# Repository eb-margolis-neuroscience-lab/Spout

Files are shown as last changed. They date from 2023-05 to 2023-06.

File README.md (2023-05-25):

# Spout
This is the general repository where all Spout related information can be found. 

Spout is a device that tracks rodent liquid consumption in a home cage environment. It can be built by any individual with minimnal soldeirng experience and is cost effective. This repository includes the [construction guide](https://github.com/eb-margolis-neuroscience-lab/Spout/tree/main/Spout_Construction_Guide), [arduino code for the device](https://github.com/eb-margolis-neuroscience-lab/Spout/tree/main/arduino%20code), and the [anaylsis software](https://github.com/eb-margolis-neuroscience-lab/Spout/tree/main/SpoutAnalyze) that was created for the device. You can find the Spout publication [here]().

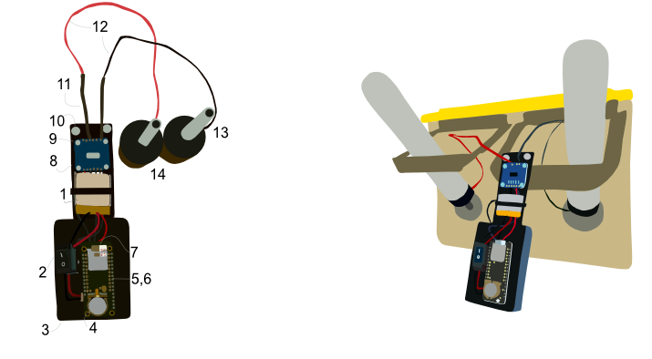
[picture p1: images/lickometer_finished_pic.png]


## [Device contruction guide](https://github.com/eb-margolis-neuroscience-lab/Spout/tree/main/Spout_Construction_Guide)

The contruction guide describes how to build the Spout device. It includes links to all the necessary components, 3D print files, wiring diagrams, soldering tutorials, and all details needed for an electrical engineering novice to build this device. Accessibility was an important factor when creating Spout. The device is cost effective and can be built by anyone, regardless of electrical engineering experience. The soldering tutorials linked in the construction guide should an adequate introcution to master the limited soldering needed to build the device. 

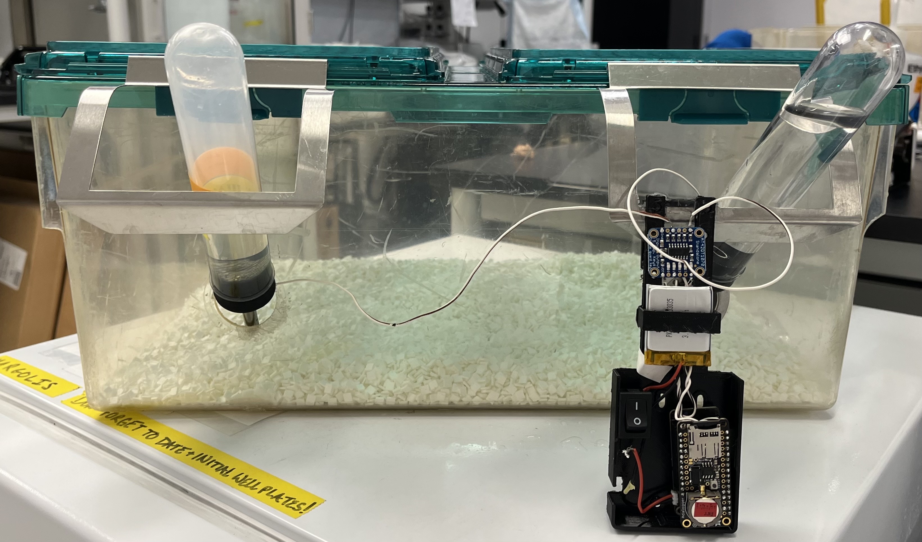
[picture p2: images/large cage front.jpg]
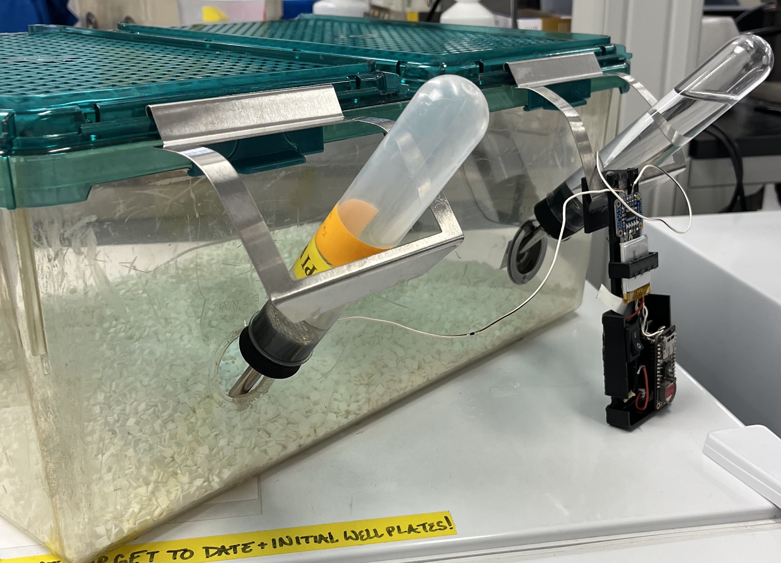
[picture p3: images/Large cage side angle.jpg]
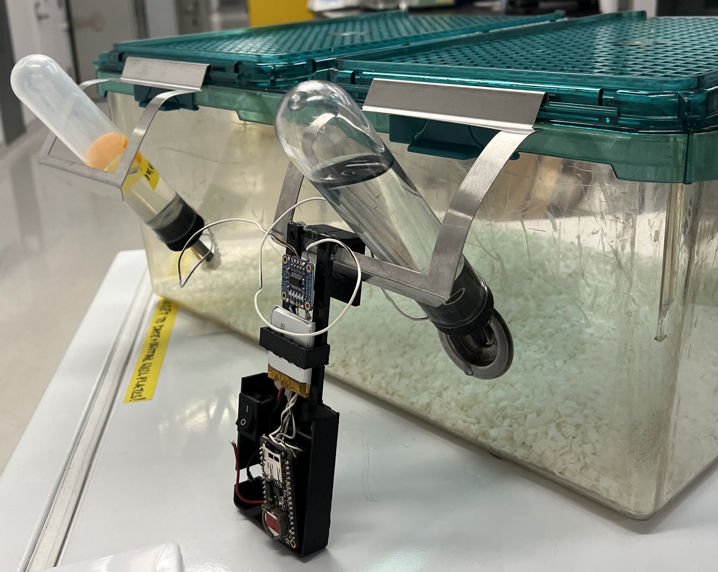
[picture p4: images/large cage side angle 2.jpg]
  

## [Code for device](https://github.com/eb-margolis-neuroscience-lab/Spout/tree/main/arduino%20code)

The arduino code folder includes the real time clock code, which must be flashed onto the device to set the coin battery clock prior to the SpoutCollect code, and the most updated C++ file (SpoutCollect.ino) that tells the device how to collect data. The user must download these files onto their computer, and then starting with pcf8523, the user uploads the two files onto the Spout device that is connected to the computer with a micro USB cable. In the arduino code folder there are links to adruino tutorials to help people that do not have much programming experience. 

## [SpoutAnalyze desktop data analysis app](https://github.com/eb-margolis-neuroscience-lab/Spout/tree/main/SpoutAnalyze)

SpoutAnalyze is the analysis software that is downloaded onto the users computer in order to analyze the collected csv files into useable data. The user takes the csv files off the microSD card that collects the data directly from the device, and uploads these files into SpoutAnalyze. SpoutAnalyze reads the csv files and produces time-locked consumption graphs, estimated total volume consumed, total bout time,  longest bout, median bout time, and drinking bout length histograms for each spout. It also has the function to summarize groups of data at once under the "analyze group" tab. This folder also includes a video tutorial explaining how to use the program.

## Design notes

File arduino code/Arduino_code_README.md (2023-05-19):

# Firmware installation  
 1. If you don't already have it, install the [Arduino IDE](https://www.arduino.cc/en/software) which will upload the compiled code to the device. Then follow the [instructions](https://learn.adafruit.com/adafruit-esp32-feather-v2/arduino-ide-setup) on the Adafruit website to install the required libraries for the Huzzah32. 
 2. The real time clock (RTC) will hold the date and time so that data can be aligned with time of day. Follow [these instructions](https://learn.adafruit.com/adafruit-pcf8523-real-time-clock/rtc-with-arduino), except the wiring part, to set the RTC. 
 3. To set the RTC, connect the Spout device to the computer with a microUSB and flash [RTC_PCF8523](https://github.com/eb-margolis-neuroscience-lab/Spout/blob/main/arduino%20code/pcf8523.ino) onto it. The clock will be set based on the time and date on the computer. To check that the clock is set and functioning open the Arduino IDE serial monitor with the device still connected to the computer. If the coin battery gets disconnected at any time, the RTC has to be flashed onto the device again. 
4. Use the Arduino IDE to flash [SpoutCollect](https://github.com/eb-margolis-neuroscience-lab/Spout/blob/main/arduino%20code/SpoutCollectMay2023.ino) onto the device. 
5. Disconnect the device from the computer and insert a micro SD card. 
6. The device is ready to use once the battery is inserted. Click [here](https://github.com/eb-margolis-neuroscience-lab/Spout/blob/main/Spout_Construction_Guide/Spout_Construction_Guide_README.md) to return to the contruction guide. 

## Helpful tutorials for Arduino IDE and C++: 

1. [Arduino IDE basics](https://docs.arduino.cc/software/ide-v1/tutorials/arduino-ide-v1-basics)

2. [Arduino IDE intro tutorial](https://docs.arduino.cc/learn/starting-guide/the-arduino-software-ide) -- This tutorial allows you to learn how to navigate Arduino IDE by creating your own blink program. This is not a needed step for using Spout, it is just a helpful resource for people that are new to Arduino and programming. 

3. [Introduction to C++ on Arduino](https://www.digikey.com/en/maker/blogs/2020/the-basics-of-c-on-an-arduino-part-1-variables)

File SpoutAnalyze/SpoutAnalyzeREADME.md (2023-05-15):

# SpoutAnalyze
A comprehensive application that works together with the SpoutCollect home cage drinking tracking device to analyze and visualize recorded data. The app is written in [`electron.js`](https://github.com/electron/electron) and runs as an independent executable. The app processes and summarizes the SpoutCollect data, output including visualing bout v time of day and estimated consumption volumes. The app also can generate reference calibrations to relate drinking duration to volume consumed.  
Graphics are generated using [`plotly.js`](https://plotly.com/javascript/), and can be saved as vector graphics. <br>

A link to the Spout journal article can be found here. (to be added)

## Example Workflow Video: Calibration Page
HomePage

## Installing
To install **SpoutAnalyze**, go to the [`SpoutJS SourceForge Page`](https://sourceforge.net/u/ahberson/profile) and follow the instructions for your computer's platform. Apple, Windows, and Linux versions are downloadable.

## Getting Started
See the Spout device construction guide to get started collecting data.

### Analyze one file

### Analyze a group of files

### Generate a calibration curve
The calibration curve function enables consumed volumes to be estimated from the drinking durations detected. The last active calibration is automatically loaded when the app is launched and is used by the "analyze" functions. Calibrations can be exported and imported in case multiple calibration curves are required by a user. <br>

We recommend collecting data from at least 8 animals (or 16 bottles) for a calibration. <br>

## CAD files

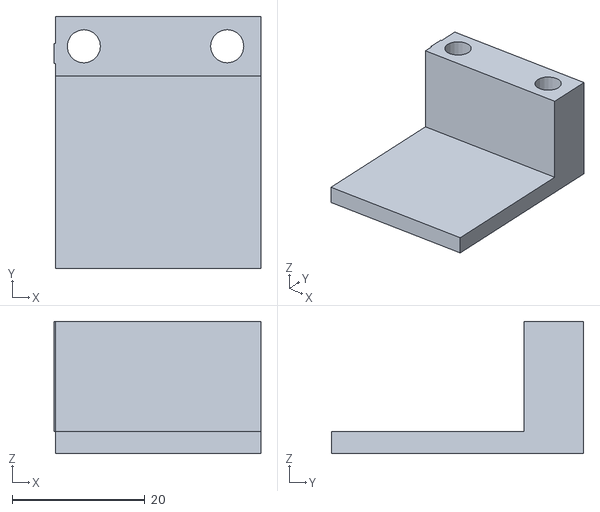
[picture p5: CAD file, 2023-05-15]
Spout_Construction_Guide/Spout hook (1).stl
31.2 x 38.0 x 19.9

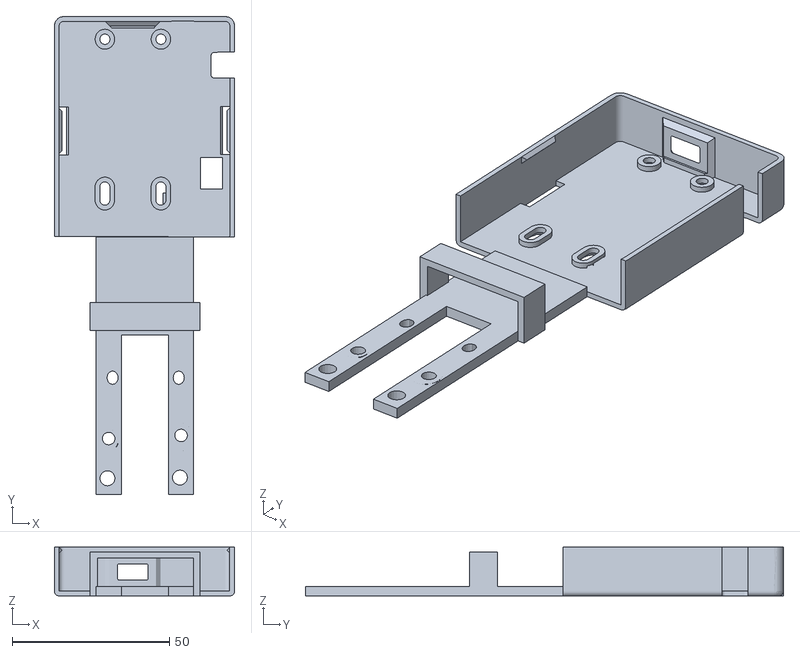
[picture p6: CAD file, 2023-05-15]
Spout_Construction_Guide/Spout body final (1).stl
57.2 x 151.8 x 15.5

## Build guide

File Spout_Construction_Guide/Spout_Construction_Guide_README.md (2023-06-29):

# Spout construction guide
This guide explains how to assemble the Margolis Lab Spout, a cost effective device that tracks rodent liquid consumption in the animal's home cage for up to two different bottles. The device collects data and the desktop app ['SpoutAnalyze'](https://github.com/eb-margolis-neuroscience-lab/SpoutJS-LIQR) analyzes it and generates visualizations. 
A link to the Spout journal article [will be] found here ()
## Materials 

| | Component | Number | Cost per unit | Total cost | Source|
|-|---|---|---|---|---|
| 1 | Lithium ion battery (capacity = 500mAh) | 1| $7.95 | $7.95 | [Adafruit Lithium Ion Battery](https://www.adafruit.com/product/1578) |
| 2 | Switch | 1 | $1.72 | $1.72 | [Switch](https://www.digikey.com/en/products/detail/triad-components-group,-inc/RF1-1B-DC-2-B-1/11492841?utm_adgroup=Triad%20Components%20Group%2C%20INC&utm_source=google&utm_medium=cpc&utm_campaign=Shopping_DK%2BSupplier_Tier%201%20-%20Block%201&utm_term=&utm_content=Triad%20Components%20Group%2C%20INC&gclid=EAIaIQobChMI2vfoy7Ca_AIVKQ2tBh3Y_wqhEAQYASABEgJIcvD_BwE) |
| 3 | 3D printed Case | 1 | Cost depends on plastic used |  | [3d Printed case]()
| 4 | Coin Battery | 1 | ~$1 | ~$1 | [Panasonic CR1220 3V coin battery](https://www.panasonic-batteries.com/en/specialty/lithium-coin/coin-lithium-cr1220) |
| 5 | Adafruit Feather Huzzah 32 | 1 | $19.95 | $19.95 | [Adafruit Feather Huzzah32](https://www.adafruit.com/product/3405) |
| 6 | Adafruit Adalogger FeatherWing | 1 | $8.95 | $8.95 | [Adafruit Adalogger Featherwing](https://www.adafruit.com/product/2922) |
| 7 | SanDisk MicroSD card 16GB | 1 | ~$5 | ~$5 | [SanDisk MicroSD 16GB 3-pack](https://www.amazon.com/SanDisk-3-Pack-microSDHC-Memory-3x16GB/dp/B089DPCJS1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) |
| 8 | Standalone 5 Key Capacitive Touch Sensor | 1 | $7.50 | $7.50 | [Adafruit capacitive touch sensor](https://www.adafruit.com/product/1362) |
| 9 | Small screws and nuts to secure boards | 8 |  | | [screws]() |
| 10 | Large screws and nuts for case | 2 | | | [large screws]() | 
| 11 | Heat shrink |  | $0.01 | $0.01 | [Heat Shrink](https://www.amazon.com/625pcs-Shrink-Tubing-Tubes-Ratio/dp/B07QM8249H?th=1) |
| 12 | Wires | 6 | $0.65/foot| $1.95 | [Stranded electrical wire](https://www.amazon.com/BNTECHGO-Silicone-Flexible-Strands-Stranded/dp/B01MFEV8SG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) |
| 13 | Metal spout | 2 | | | [metal sipper tube](https://www.altdesign.com/products/rodent-ivc/rodent-ivc-accessories/watering-options/water-bottles/water-bottle-sipper-tubes/straight-tube-with-ball-stainless-steel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) |
| 14 | Rubber stopper with hole | 2 | | | [rubber stopper with hole](https://www.fishersci.com/shop/products/rubber-stopper-size-6-1-hole-5mm-diameter/S24600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) |

## Case 
The 3D print files for the case can be found here: [Spout body](https://github.com/eb-margolis-neuroscience-lab/lick-o-meter-construction-guide/blob/main/Spout%20body%20final.stl) and [Spout hook](https://github.com/eb-margolis-neuroscience-lab/lick-o-meter-construction-guide/blob/main/Spout%20hook.stl)

Use 2 large screws to secure the neck of the case to the hook so that Spout can hang off the homecage. See [Securing the boards to the case](https://github.com/eb-margolis-neuroscience-lab/lick-o-meter-construction-guide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) for more information. 

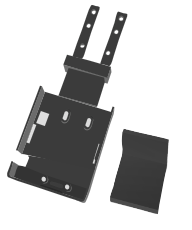
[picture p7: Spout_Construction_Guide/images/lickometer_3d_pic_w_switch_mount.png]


## Wiring the adafruit and adalogger boards 

1. Solder the female headers to the Huzzah32 Board. Soldering tips can be found here: ['How_to_solder'](https://www.youtube.com/watch?v=6rmErwU5E-k) ['Soldering_headers'](https://learn.adafruit.com/how-to-solder-headers/overview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) 
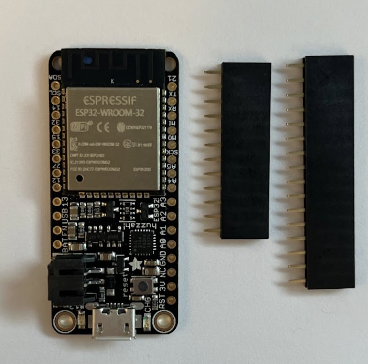
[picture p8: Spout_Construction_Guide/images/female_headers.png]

2. Solder the male headers to the adalogger feather board.
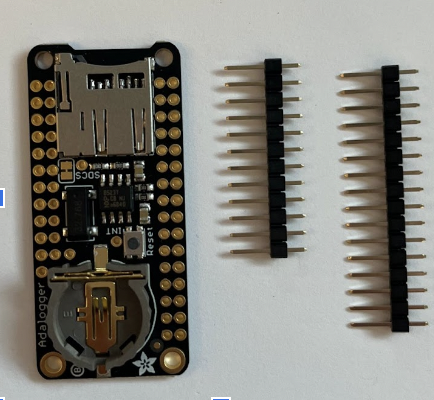
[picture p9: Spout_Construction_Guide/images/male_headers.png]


3. Solder four wires to their respective pins on the Adalogger feather board. The wires are soldered to the adalogger board, but the Huzzah32 board has the pin labels. Solder the wires such that wire 1 is attached to the ground pin (**GND**) wire 2 is attached to power pin (**3V**), and the two input signal wires are attached to pins **A0** and **A7**. 

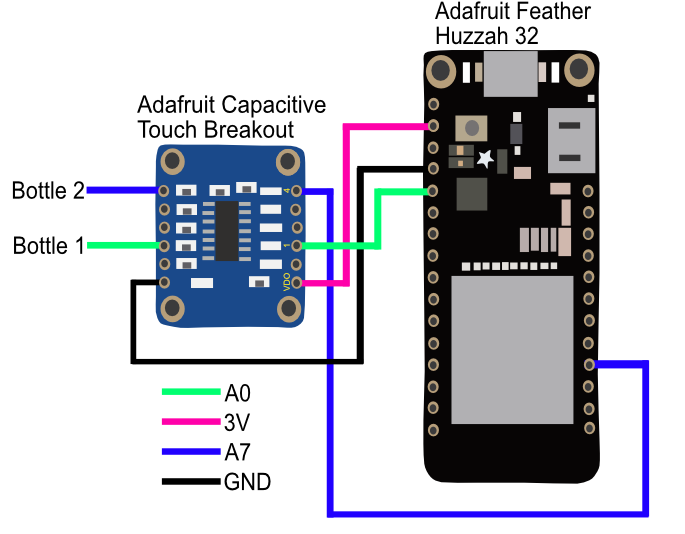
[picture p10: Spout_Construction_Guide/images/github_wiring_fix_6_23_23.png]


4. Solder the other ends of the four wires to their pins on the **output** side of the Capacitive touch breakout board. **3V** to **VDO**, **GND** to **GND**, **A7** to pin **4**, **A0** to pin **1**. 

### How to modify the wires to fit your metal bottle spouts:
 
 Take two wires and strip 2.5-3 cm of the insulation from one end. Wrap the exposed wire around the base of your metal bottle spout. Solder the wire in a circle that fits snugly around the metal sipper tube. 

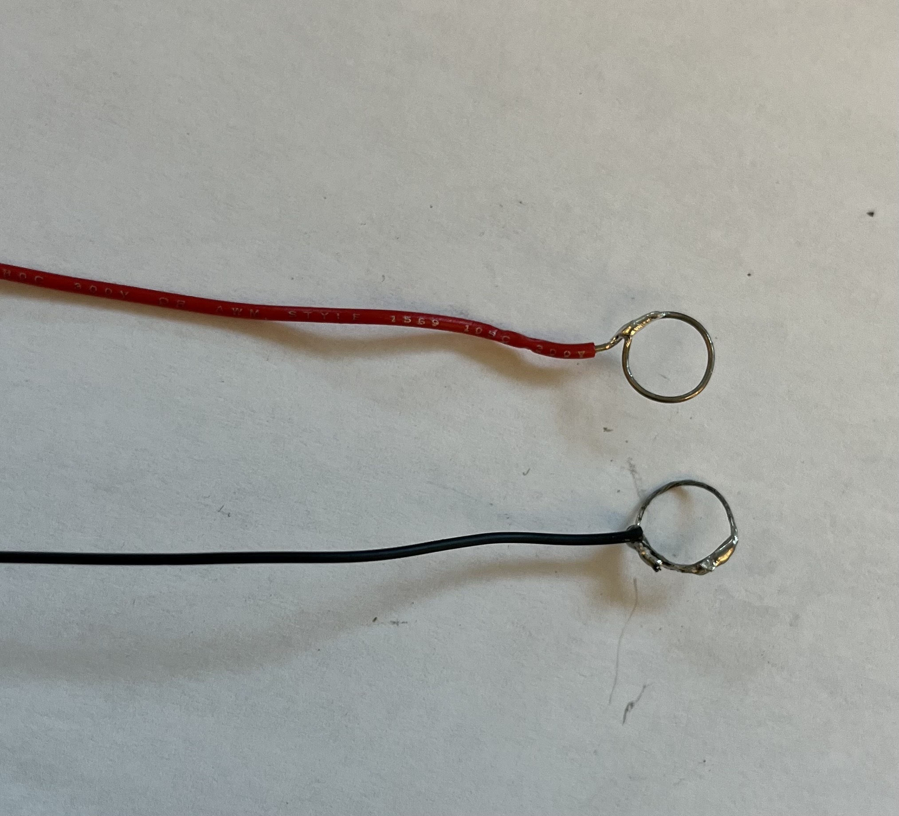
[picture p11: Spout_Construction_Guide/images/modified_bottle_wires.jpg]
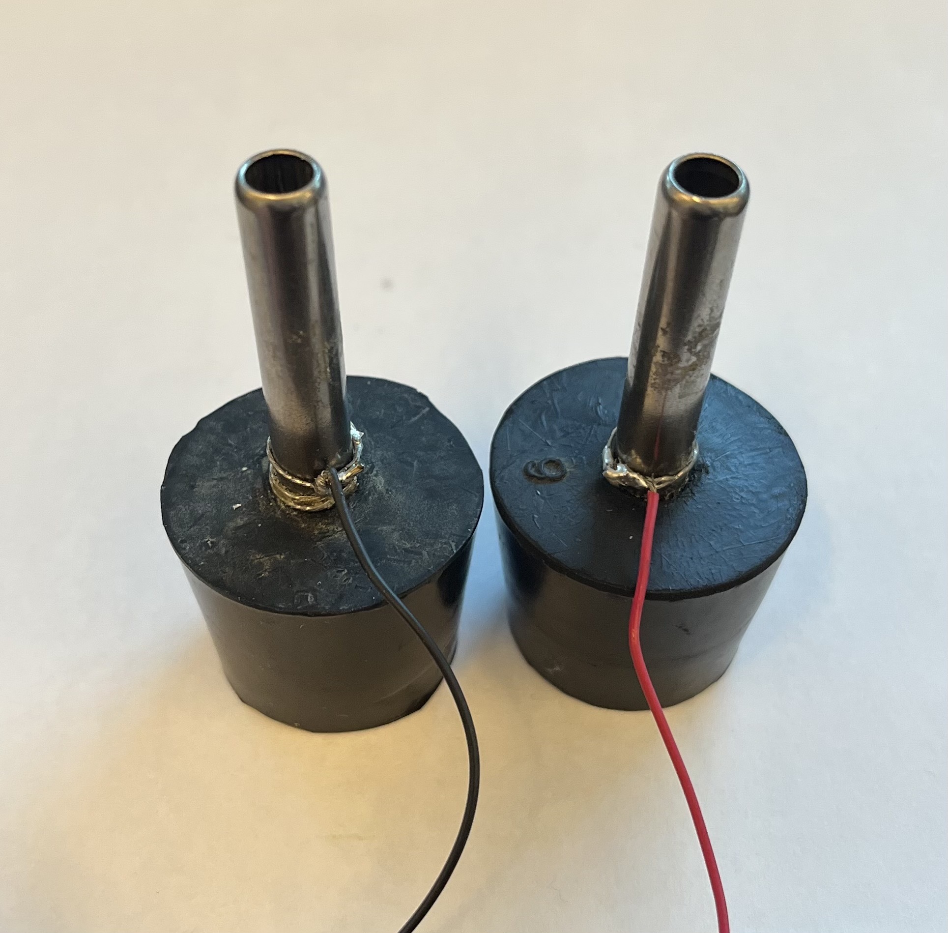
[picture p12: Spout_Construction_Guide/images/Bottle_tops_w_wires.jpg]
  

### How to reinforce bottle wire connections
 
 Next these modified wires need to be soldered to the **input** side of the capacitive touch breakout board. This connection undergoes significant and repetitive strain as the bottles are placed and removed. Reinforcement is optional, but we recommend it. You may choose to skip to **step 5**. 
1. Strip about 1.5 cm of coating off the non-modified ends of the bottle wires.

2. Take 2.5 cm long pieces of heat shrink and feed them over each wire.
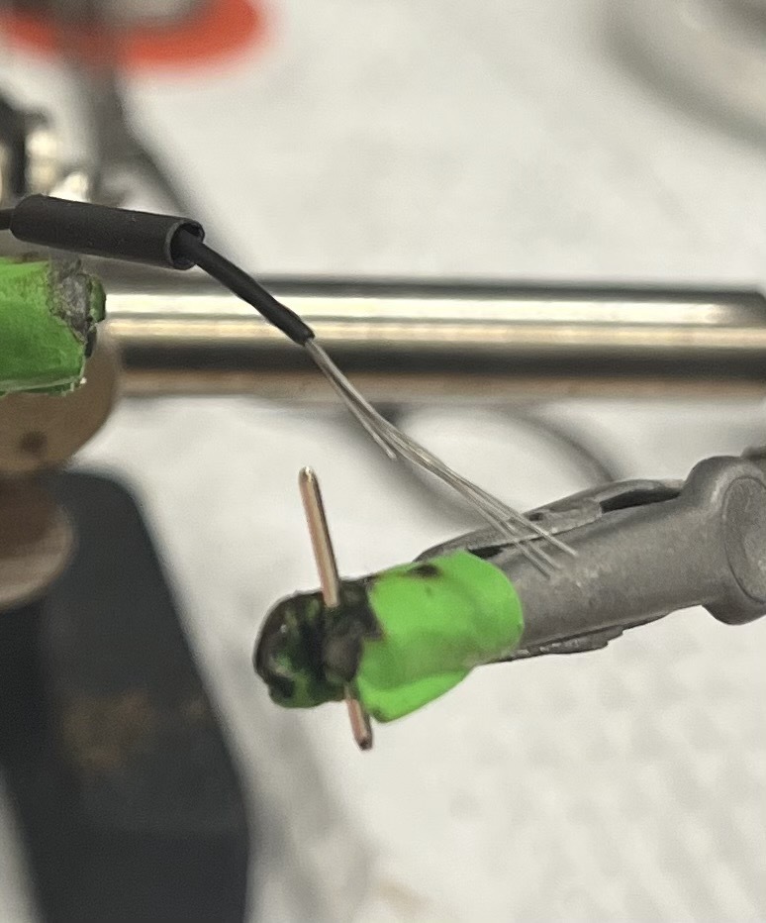
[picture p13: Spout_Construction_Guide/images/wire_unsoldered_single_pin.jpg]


3. Take one single male header pin and solder the long end of the pin to the exposed wire. Repeat on other wire. 
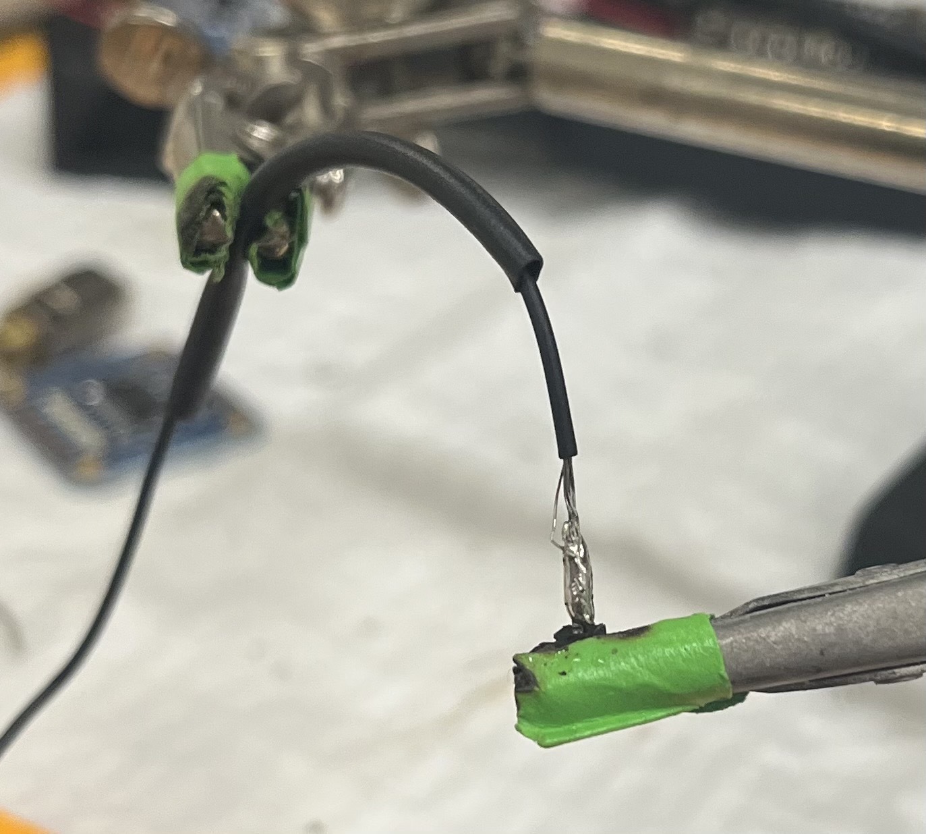
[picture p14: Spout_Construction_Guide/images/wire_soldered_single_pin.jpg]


4. Move heat shrink over the soldered connection between the wire and the male header pin. Heat to secure. Reapeat on other wire. 

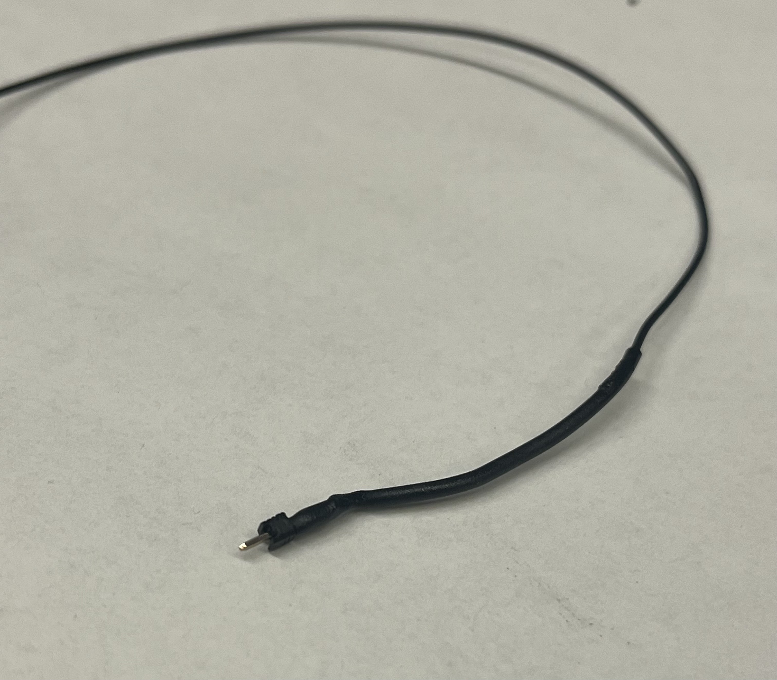
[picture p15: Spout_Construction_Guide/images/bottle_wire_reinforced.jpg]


5. Solder the two modified bottle spout wires to pins **1** and **4** on the **input** side of the Adafruit capacitive touch breakout board. If you reinforced the bottle spout wire connection, solder the short ends of the male header pins into pins 1 and 4. 

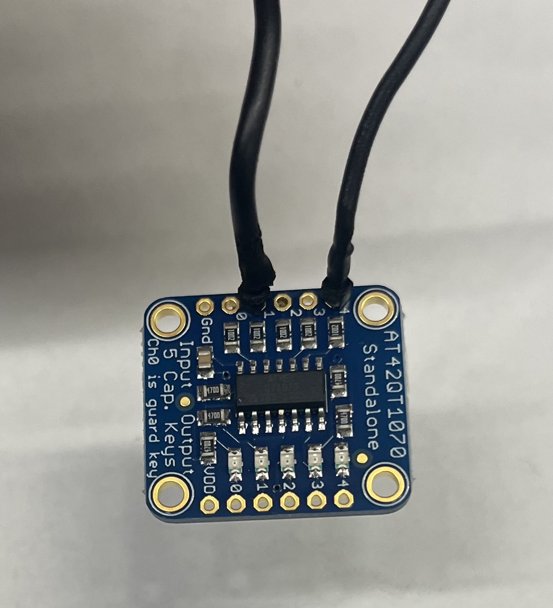
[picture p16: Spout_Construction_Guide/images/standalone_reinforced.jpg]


6. Stack the Adalogger board on top of the Huzzah32 board, lining them up by the header pins. 

7. Insert the coin cell battery into the Adalogger feather board. Note: This battery powers the real time clock (RTC), not the device. This battery is expected to last at least a year, if not longer, but if the date on your Spout files is incorrect, the battery is likely be dead. 

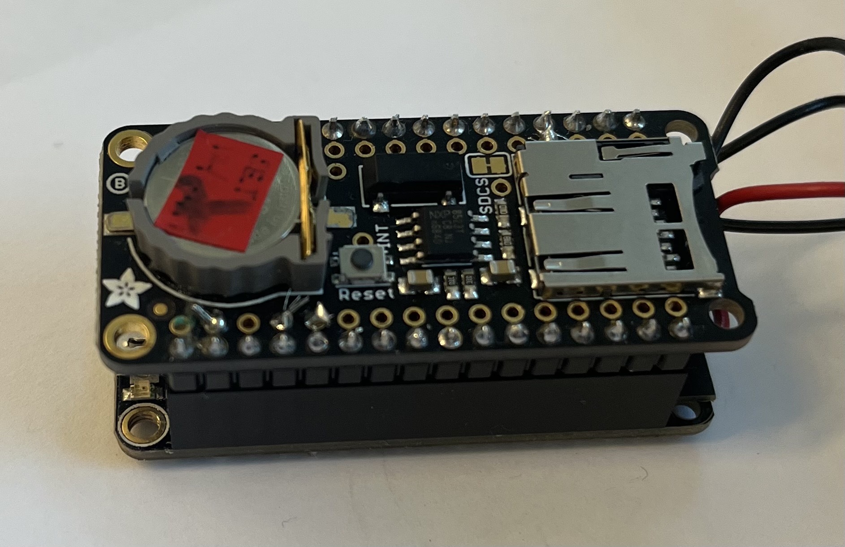
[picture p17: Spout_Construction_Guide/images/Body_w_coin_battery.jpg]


## Securing the boards to the case 

Using screws secure the Huzzah32 and Feather boards to the base of the case and the capacitive sensor board to the neck of the case. 

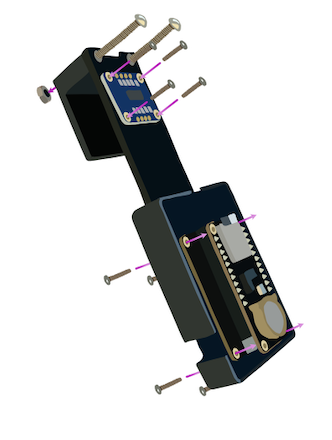
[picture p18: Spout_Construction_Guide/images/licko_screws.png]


## Adding a switch to the lithium battery 

The SpoutCollect device starts writing data immediately when it is powered on. In order to easily start and stop the device after it is mounted in place on the cage we add a switch to the lithium battery that powers the device. We have found that a 3.7 V 500 mAh Li-ion battery is sufficient to run the device for well over 24 hr. Larger capacity batteries can be used as well, as long as the connector is compatible with the Huzzah32. 

1. Cut the **red wire** of the battery at its halfway point. Strip 1 cm of wire insulation from each of the ends just created.

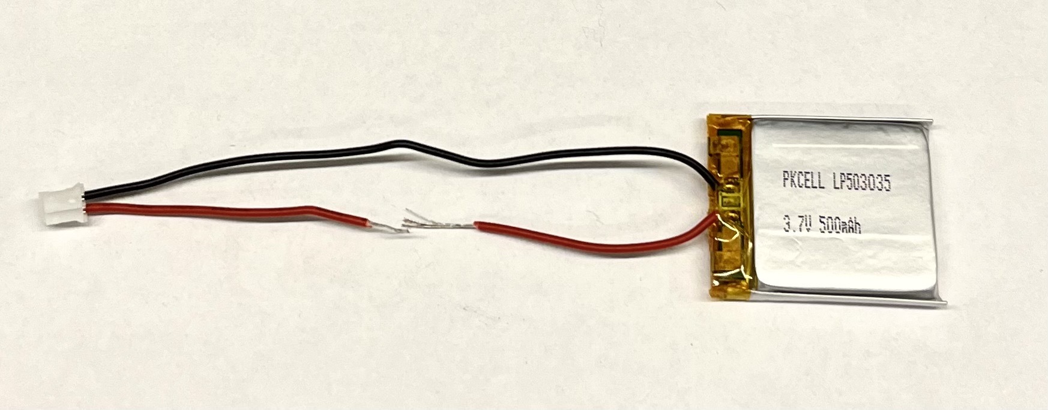
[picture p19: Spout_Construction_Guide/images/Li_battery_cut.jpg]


2. Solder these ends to the leads on the switch.

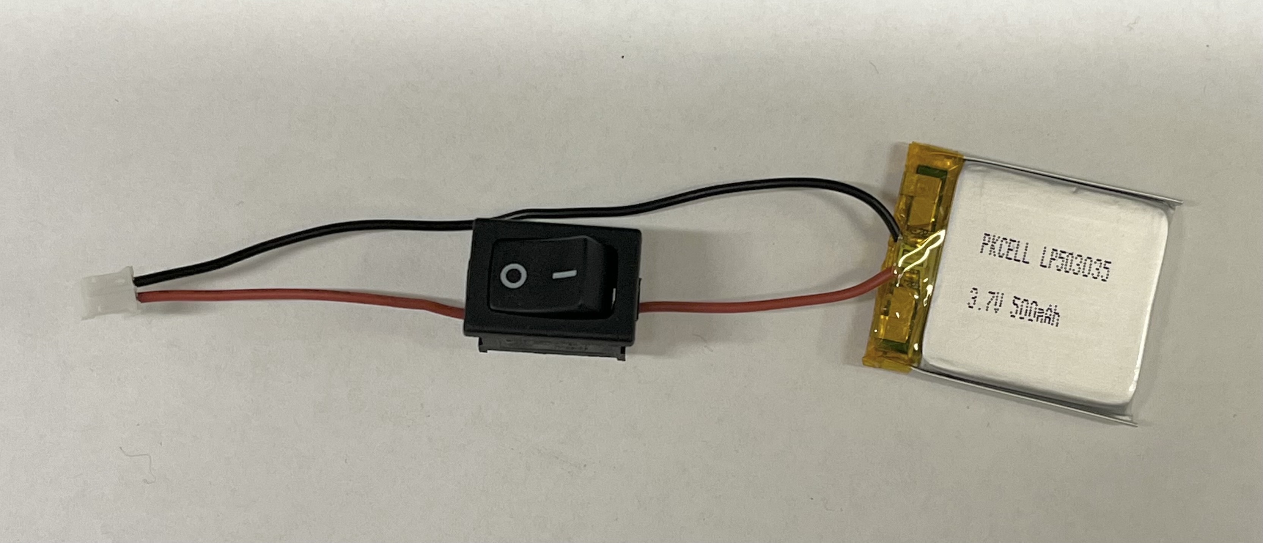
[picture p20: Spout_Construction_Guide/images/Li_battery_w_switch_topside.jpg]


3. The battery slides under the plastic arch on the neck of the case and the legs of the battery fit into the square hole on the body of the case next to the Huzzah32. See graphic below. 

Make sure the switch is in the **ON position** when charging. Charging is acomplished through the micro USB connector.

## Firmware installation  
 1. If you don't already have it, install the [Arduino IDE](https://www.arduino.cc/en/software) which will upload the compiled code to the device. then follow the [instructions](https://learn.adafruit.com/adafruit-esp32-feather-v2/arduino-ide-setup) on the Adafruit website to install the required libraries for the Huzzah32. 
 2. The real time clock (RTC) will hold the date and time so that data can be aligned with time of day. Follow [these instructions](https://learn.adafruit.com/adafruit-pcf8523-real-time-clock/rtc-with-arduino), except the wiring part, to prepare to set the RTC. 
 3. To set the RTC, connect the Spout device to the computer and flash [RTC_PCF8523](https://github.com/eb-margolis-neuroscience-lab/lick-o-meter-construction-guide/blob/main/pcf8523.ino) onto it. The clock will be set based on the time and date on the computer. To check that the clock is set and functioning open the Arduino IDE serial monitor with the device still connected to the computer. 
4. Use the Arduino IDE to flash [SpoutCollect](https://github.com/eb-margolis-neuroscience-lab/lick-o-meter-construction-guide/blob/main/SpoutCollectOct2022.ino) onto the device. 
5. Disconnect the device from the computer and insert a micro SD card. 

## Hanging your device on the homecage 
Here are some images that show how to hang the Spout on two different types of cages: 

  

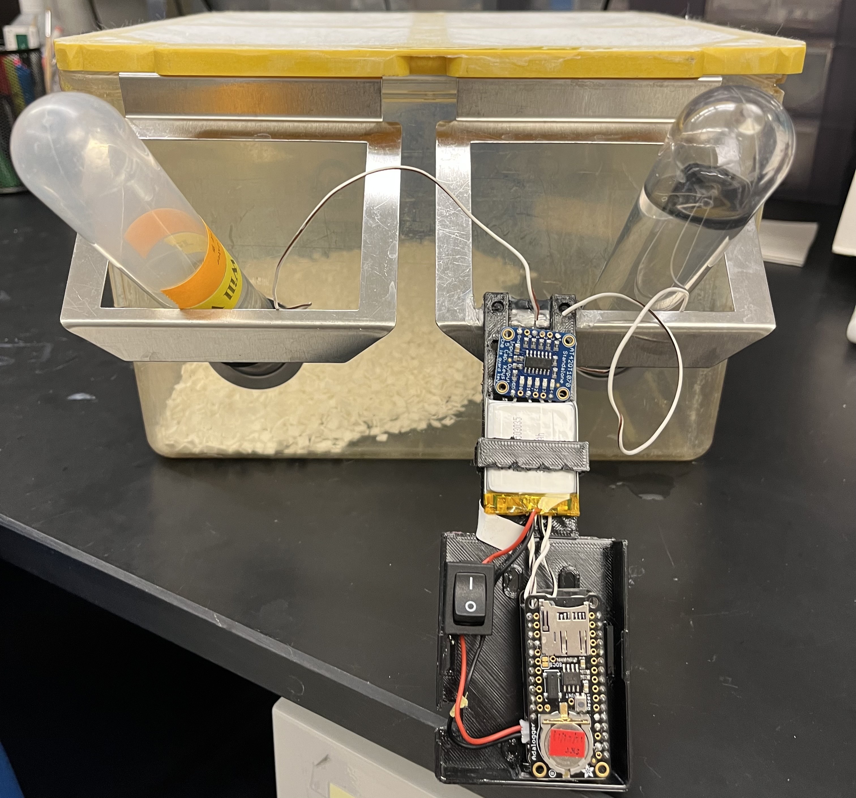
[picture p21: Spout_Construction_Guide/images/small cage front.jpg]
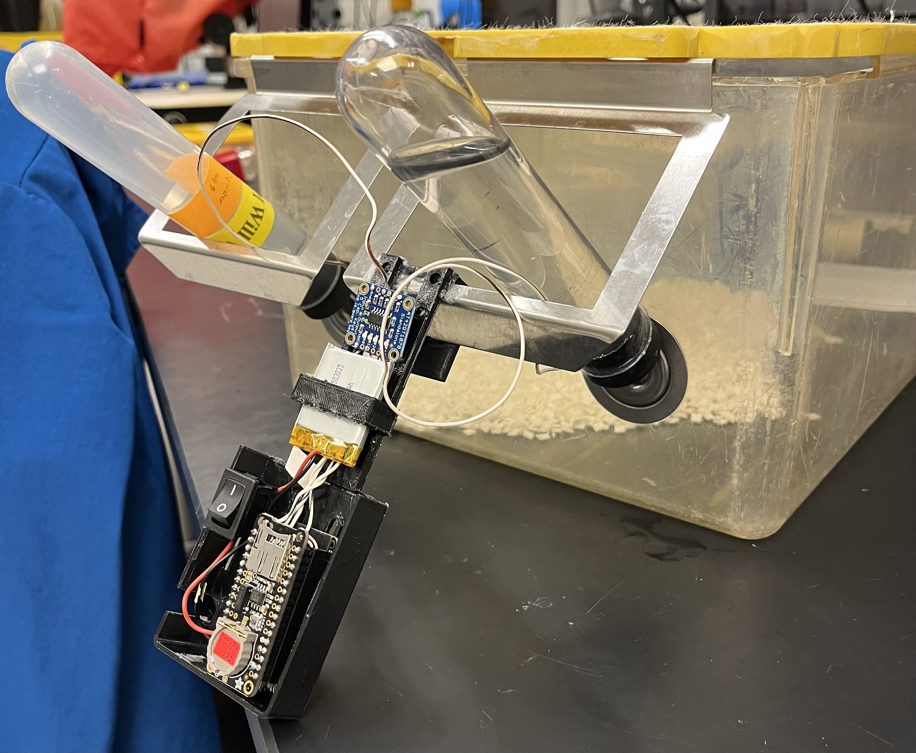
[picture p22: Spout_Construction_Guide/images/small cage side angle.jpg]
 

## Your device is ready for use!

To use, hang on home cage and turn battery switch to ON. To transfer collected data to the computer for analysis remove the microSD card and connect it to the computer using a card reader or adapter. 



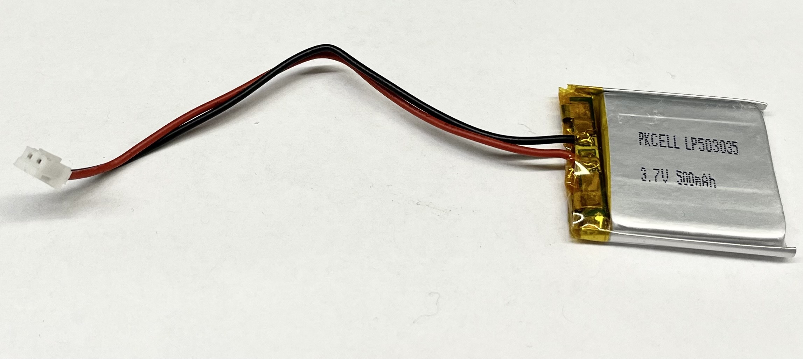
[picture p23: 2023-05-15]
Spout_Construction_Guide/images/Li_Battery_uncut.jpg

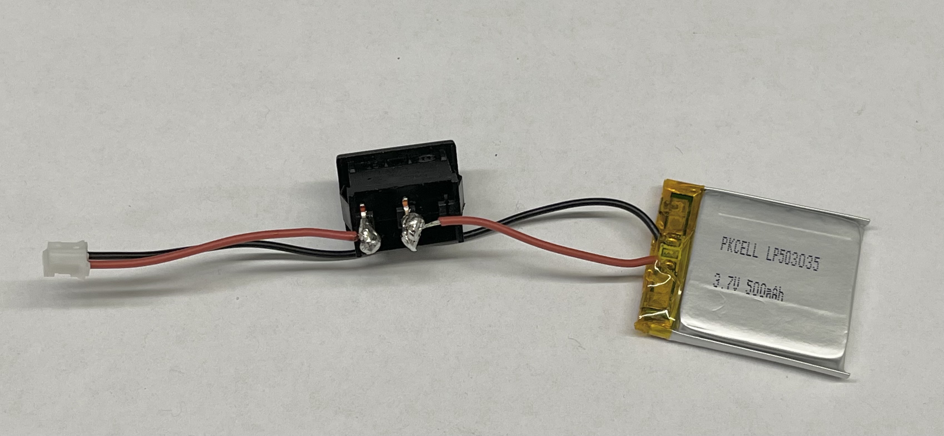
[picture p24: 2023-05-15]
Spout_Construction_Guide/images/Li_battery_with_switch_solder_side.jpg

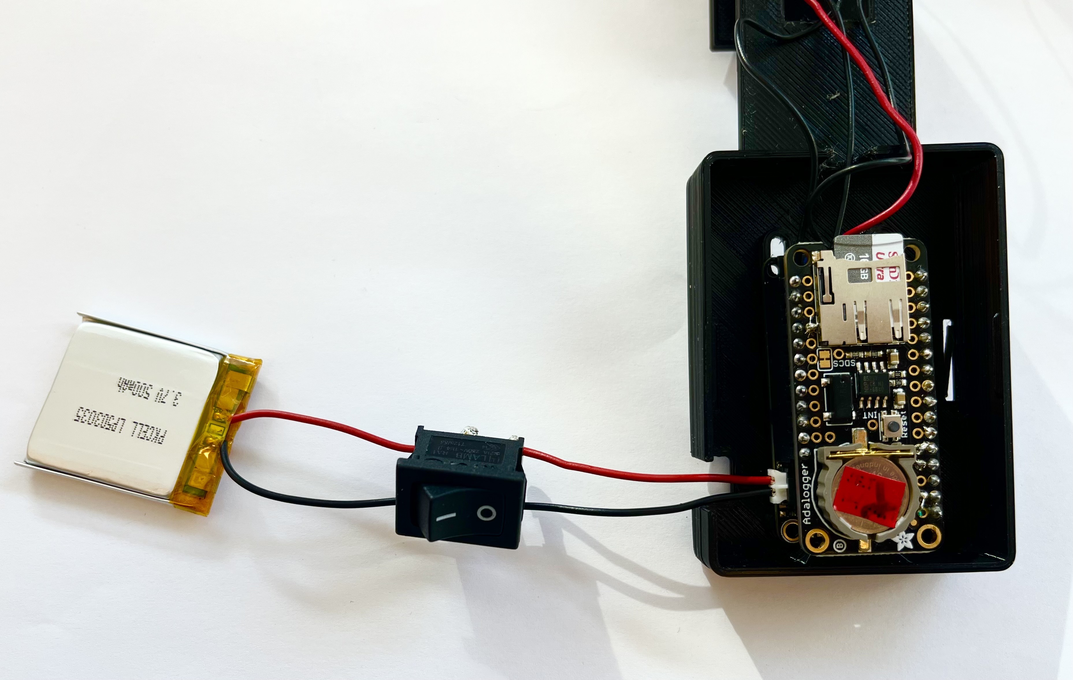
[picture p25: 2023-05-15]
Spout_Construction_Guide/images/Li_battery_with_switch.jpg

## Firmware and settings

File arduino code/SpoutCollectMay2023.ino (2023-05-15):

//SpoutCollect v 0.9.22
//Firmware for rodent cage mounted drinking tracker, capacitative touch detection
//See hardware details at [insert Github link here] 
//Last updated by EBM 5/06/2023

#include <Wire.h>
#include "RTClib.h"
#include "FS.h"
#include "SD.h"
#include "SPI.h"
#include <time.h>
#include <String.h>

RTC_PCF8523 rtc;

char daysOfTheWeek[7][12] = {"Sunday", "Monday", "Tuesday", "Wednesday", "Thursday", "Friday", "Saturday"};
char monthsOfTheYear[13][12] = {"", "January", "February", "March", "April", "May", "June", "July", "August", "September", "October", "November", "December"};

const int TOUCH_RED = A0; //connect breakout pad to pin A0
const int TOUCH_BLACK = A7; //connect breakout pad to pin A7

//GPIO bitmask calculation for sleep functionality
#define BLACK_PIN_BITMASK 0x100000000

float BatteryVoltage = 0;
char filenameSTR[] = "00000000.csv";
const int touch_threshold = 100;

//This device name, used in naming of files
String fname = "Cage1";

//---------------------------------------------------
void setup()
{
  Serial.begin(115200);
  // Initialize SD Card
  if (!SD.begin(33)) {
    Serial.println("Card Mount Failed");
    return;
  }
  uint8_t cardType = SD.cardType();
  if (cardType == CARD_NONE) {
    Serial.println("No SD card attached");
    return;
  }

  //Check RTC
  if (! rtc.begin()) {
    Serial.println("Couldn't find RTC");
    while (1);
  }
  if (! rtc.initialized()) {
    Serial.println("RTC is NOT running!");
  }
  
  //Get start time and date, name datafile accordingly
  DateTime now = rtc.now();
  char dateTimeString[200] = "";
  sprintf(dateTimeString, "%s, %s %d %04d %02d:%02d:%02d", daysOfTheWeek[now.dayOfTheWeek()], monthsOfTheYear[now.month()], now.day(), now.year(), now.hour(), now.minute(), now.second());
  String timestamp = "Begin data collection at ";
  timestamp += dateTimeString;
  String dataString = "";
  dataString += "Touch value BLACK, ";
  dataString += "Touch value RED, ";
  dataString += "Time (ms)";
//  dataString += ", Battery voltage";
//filenamestring must start with / and include _ between device name and timestamp
  String thisfilename = "/";
char filedate ;
  thisfilename = thisfilename + fname + "_"; 
  sprintf(filedate, "%dMonth%dDay%dHour%dMinute.csv", now.month(), now.day(), now.hour(), now.minute());
  thisfilename = thisfilename + filedate; 
  
  //devicename must be followed by "_" in order for SpoutAnalyze to parse the device name correctly
//  sprintf(filenameSTR, thisfilename);
  File dataFile = SD.open(thisfilename, FILE_WRITE); 
  if (dataFile) {
    dataFile.println(timestamp); //write the time of data collection start
    dataFile.println(dataString); //write column names
    //Serial.println(filenameSTR); //write file name to serial monitor for troubleshooting
  }
  else {
    Serial.println("error creating file in setup");
    Serial.println(filenameSTR);
  }
  dataFile.close();

  //Setup sleep/wake functionality, reading goes low when touched
  esp_sleep_enable_ext1_wakeup(BLACK_PIN_BITMASK, ESP_EXT1_WAKEUP_ALL_LOW); //wake if Black spout touched
  esp_sleep_enable_ext0_wakeup(GPIO_NUM_26, 0); //wake if Red spout touched, on Feather HUZZAH ESP32 A0 = GPIO26
}

//---------------------------------------------------
void loop()
{
  //Read value from each touch sensor
  int touch_value_black = analogRead(TOUCH_BLACK);
  int touch_value_red = analogRead(TOUCH_RED);
  //test if touch value(s) are low, write data to the .csv
  //columns are: touch_value_black, touch_value_red, time since start in ms, battery voltage
  if (touch_value_black < touch_threshold) {
    //Read battery value, convert to voltage; pin A13/I35 = Batt pin
    //  BatteryVoltage = (((analogRead(A13)) * 2 * 3.3 * 1.1) / 4095); 
      String dataString = "";
      dataString += touch_value_black;
      dataString += ", ";
      dataString += touch_value_red;
      dataString += ", ";
      dataString += millis();
    //  dataString += ", ";
    //  dataString += BatteryVoltage;
      //write value of each sensor and battery voltage 
      File dataFile = SD.open(filenameSTR, FILE_APPEND);
      dataFile.println(dataString);
    //  Serial.println(dataString); //uncomment this line to use serial monitor
    }
  else if (touch_value_red < touch_threshold) {
    //  BatteryVoltage = (((analogRead(A13)) * 2 * 3.3 * 1.1) / 4095); 
      String dataString = "";
      dataString += touch_value_black;
      dataString += ", ";
      dataString += touch_value_red;
      dataString += ", ";
      dataString += millis();
     // dataString += ", ";
     // dataString += BatteryVoltage;
      File dataFile = SD.open(filenameSTR, FILE_APPEND);
      dataFile.println(dataString);
    //  Serial.println(dataString); //uncomment this line to use serial monitor
    }
  else {
    //  Serial.println("Sleep"); //uncomment this line to use serial monitor
      esp_light_sleep_start(); //will wake on touch 
  }
}

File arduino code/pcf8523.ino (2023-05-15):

// Date and time functions using a PCF8523 RTC connected via I2C and Wire lib
#include "RTClib.h"

RTC_PCF8523 rtc;

char daysOfTheWeek[7][12] = {"Sunday", "Monday", "Tuesday", "Wednesday", "Thursday", "Friday", "Saturday"};

void setup () {
  Serial.begin(57600);

#ifndef ESP8266
  while (!Serial); // wait for serial port to connect. Needed for native USB
#endif

  if (! rtc.begin()) {
    Serial.println("Couldn't find RTC");
    Serial.flush();
    while (1) delay(10);
  }

  if (! rtc.initialized() || rtc.lostPower()) {
    Serial.println("RTC is NOT initialized, let's set the time!");
    // When time needs to be set on a new device, or after a power loss, the
    // following line sets the RTC to the date & time this sketch was compiled
   // rtc.adjust(DateTime(F(__DATE__), F(__TIME__)));
    // This line sets the RTC with an explicit date & time, for example to set
    // January 21, 2014 at 3am you would call:
    // rtc.adjust(DateTime(2014, 1, 21, 3, 0, 0));
    //
    // Note: allow 2 seconds after inserting battery or applying external power
    // without battery before calling adjust(). This gives the PCF8523's
    // crystal oscillator time to stabilize. If you call adjust() very quickly
    // after the RTC is powered, lostPower() may still return true.
  }

  // When time needs to be re-set on a previously configured device, the
  // following line sets the RTC to the date & time this sketch was compiled
   rtc.adjust(DateTime(F(__DATE__), F(__TIME__)));
  // This line sets the RTC with an explicit date & time, for example to set
  // January 21, 2014 at 3am you would call:
  // rtc.adjust(DateTime(2014, 1, 21, 3, 0, 0));

  // When the RTC was stopped and stays connected to the battery, it has
  // to be restarted by clearing the STOP bit. Let's do this to ensure
  // the RTC is running.
  rtc.start();

   // The PCF8523 can be calibrated for:
  //        - Aging adjustment
  //        - Temperature compensation
  //        - Accuracy tuning
  // The offset mode to use, once every two hours or once every minute.
  // The offset Offset value from -64 to +63. See the Application Note for calculation of offset values.
  // https://www.nxp.com/docs/en/application-note/AN11247.pdf
  // The deviation in parts per million can be calculated over a period of observation. Both the drift (which can be negative)
  // and the observation period must be in seconds. For accuracy the variation should be observed over about 1 week.
  // Note: any previous calibration should cancelled prior to any new observation period.
  // Example - RTC gaining 43 seconds in 1 week
  float drift = 43; // seconds plus or minus over oservation period - set to 0 to cancel previous calibration.
  float period_sec = (7 * 86400);  // total obsevation period in seconds (86400 = seconds in 1 day:  7 days = (7 * 86400) seconds )
  float deviation_ppm = (drift / period_sec * 1000000); //  deviation in parts per million (μs)
  float drift_unit = 4.34; // use with offset mode PCF8523_TwoHours
  // float drift_unit = 4.069; //For corrections every min the drift_unit is 4.069 ppm (use with offset mode PCF8523_OneMinute)
  int offset = round(deviation_ppm / drift_unit);
  // rtc.calibrate(PCF8523_TwoHours, offset); // Un-comment to perform calibration once drift (seconds) and observation period (seconds) are correct
  // rtc.calibrate(PCF8523_TwoHours, 0); // Un-comment to cancel previous calibration

  Serial.print("Offset is "); Serial.println(offset); // Print to control offset

}

void loop () {
    DateTime now = rtc.now();

    Serial.print(now.year(), DEC);
    Serial.print('/');
    Serial.print(now.month(), DEC);
    Serial.print('/');
    Serial.print(now.day(), DEC);
    Serial.print(" (");
    Serial.print(daysOfTheWeek[now.dayOfTheWeek()]);
    Serial.print(") ");
    Serial.print(now.hour(), DEC);
    Serial.print(':');
    Serial.print(now.minute(), DEC);
    Serial.print(':');
    Serial.print(now.second(), DEC);
    Serial.println();

    Serial.print(" since midnight 1/1/1970 = ");
    Serial.print(now.unixtime());
    Serial.print("s = ");
    Serial.print(now.unixtime() / 86400L);
    Serial.println("d");

    // calculate a date which is 7 days, 12 hours and 30 seconds into the future
    DateTime future (now + TimeSpan(7,12,30,6));

    Serial.print(" now + 7d + 12h + 30m + 6s: ");
    Serial.print(future.year(), DEC);
    Serial.print('/');
    Serial.print(future.month(), DEC);
    Serial.print('/');
    Serial.print(future.day(), DEC);
    Serial.print(' ');
    Serial.print(future.hour(), DEC);
    Serial.print(':');
    Serial.print(future.minute(), DEC);
    Serial.print(':');
    Serial.print(future.second(), DEC);
    Serial.println();

    Serial.println();
    delay(3000);
}
